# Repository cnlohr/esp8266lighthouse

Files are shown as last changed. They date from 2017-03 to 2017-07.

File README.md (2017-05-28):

# esp8266lighthouse

## Project log as of 5/28/17

So, general summary / log for esp8266lighthouse:   It works.  Surprisingly well.

1. If the base station is too close, it the signal quality gets pretty rough.   Too close = 0.8 meters or closer.  This may not be resolvable without a different opamp.  I don't know yet. 
2. There are some corner cases that will cause the ESP to freeze.  This is sad-making, however shouldn't be hard to troubleshoot.
3. The algorithm I'm using to determine frequency seems SLIGHTLY dependent on strength.  When pointed directly at the lighthouse and close, it seems to read slightly high (by about 10-15 kHz)  When at glancing angle or barely visible, it reads spot on.
4. The noise issue due to the ESP is really confusing to me.  Arbitrary moving something or switching power plugs around drastically changes the performance of the system.
5. The ESP8266 will draw ~14mA even in modem-sleep mode all the time if it is monitoring for a lighthouse.  This is sad.  I want to move to an FPGA, but because of the pinout on the ICE40 FPGAs and the fact they never put them in a reasonable package, PCBs for them cost about 10x what normal PCBs cost.
6. Though I can precisely tell frequencies, I cannot simultaneously decode pulses. Each pulse must have about 2uS between them in order to be treated as different pulses.   If we run lighthouses asynchronously, there will be some collisions.  They will need to be ignored.
7. The base stations CAN be run asynchronously and at different rates.  It seems to me that if the lighthouses are operating at the same frequency, they cannot disambiguate asynchronous pulses, but, we should be able to.

## Internal notes:

```
NOTES for transimpedence2/3
TESTS Performed with no C1, TSV992
Making R4 220k instead of 47k seeems to have little effect, but does make it worse.
Switching R1 for 47k just makes it appear drunk. There's some weird feedback thing going on.
    Like it tuned wrong or something.   Making it 10k quiets the signal a lot.
REMOVING C4 no apparent impact.

R5=10k, C5=10p -> R5=4.7k, C5=18p =>> Improvement.
Adding C1=1pF decreases amplitude a little bit but also cleans up edges.
Removing C6 seems to reduce amplitude slightly.

Far peak:
C1 none C6 none => .1238V noise, .998V Far Light
C1 none C6 1pF    => .1238V noise, .498V Far Light
C1 1pF  C6 none => .1135V noise, .358V Far Light
C1 1pF C6 1pF     => .087V Noise, .202V Far Light

Recommendation: Remove C6, C1.

Out of the following op amps...
TSH82, TSV992, AD8052, TSH22, TSH462,
TSV992 demolished.

Useful photodiodes:
PART / NOISE / FAR / Cost
PD70-01C/TR7:  .159 / .418 / .47
PD438C: .237 / .550 / .39
QSD2030F: .216 / .5363 / .30
BPW34/S-Z: .283 / .6345 /.497
PD15-216/TR8: UNUSABLE
VBPW34FAS: .175 / .815 / .778
VBPW34FASR: .2631 / .644 / .778
BPW34: .237 / .577 / .62
PD15-22C/TR8: Unworkable.
PD15-22B/TR8: Unworkable.
PD70-TR10: .2063 / .4024 / .41
BPW46: .247 / .968 / .61

Winners: BPW46, BPW34/S-Z, BPW34FAS + VBPW34FASR
Major Winners: BPW46/VBPW34FAS
```

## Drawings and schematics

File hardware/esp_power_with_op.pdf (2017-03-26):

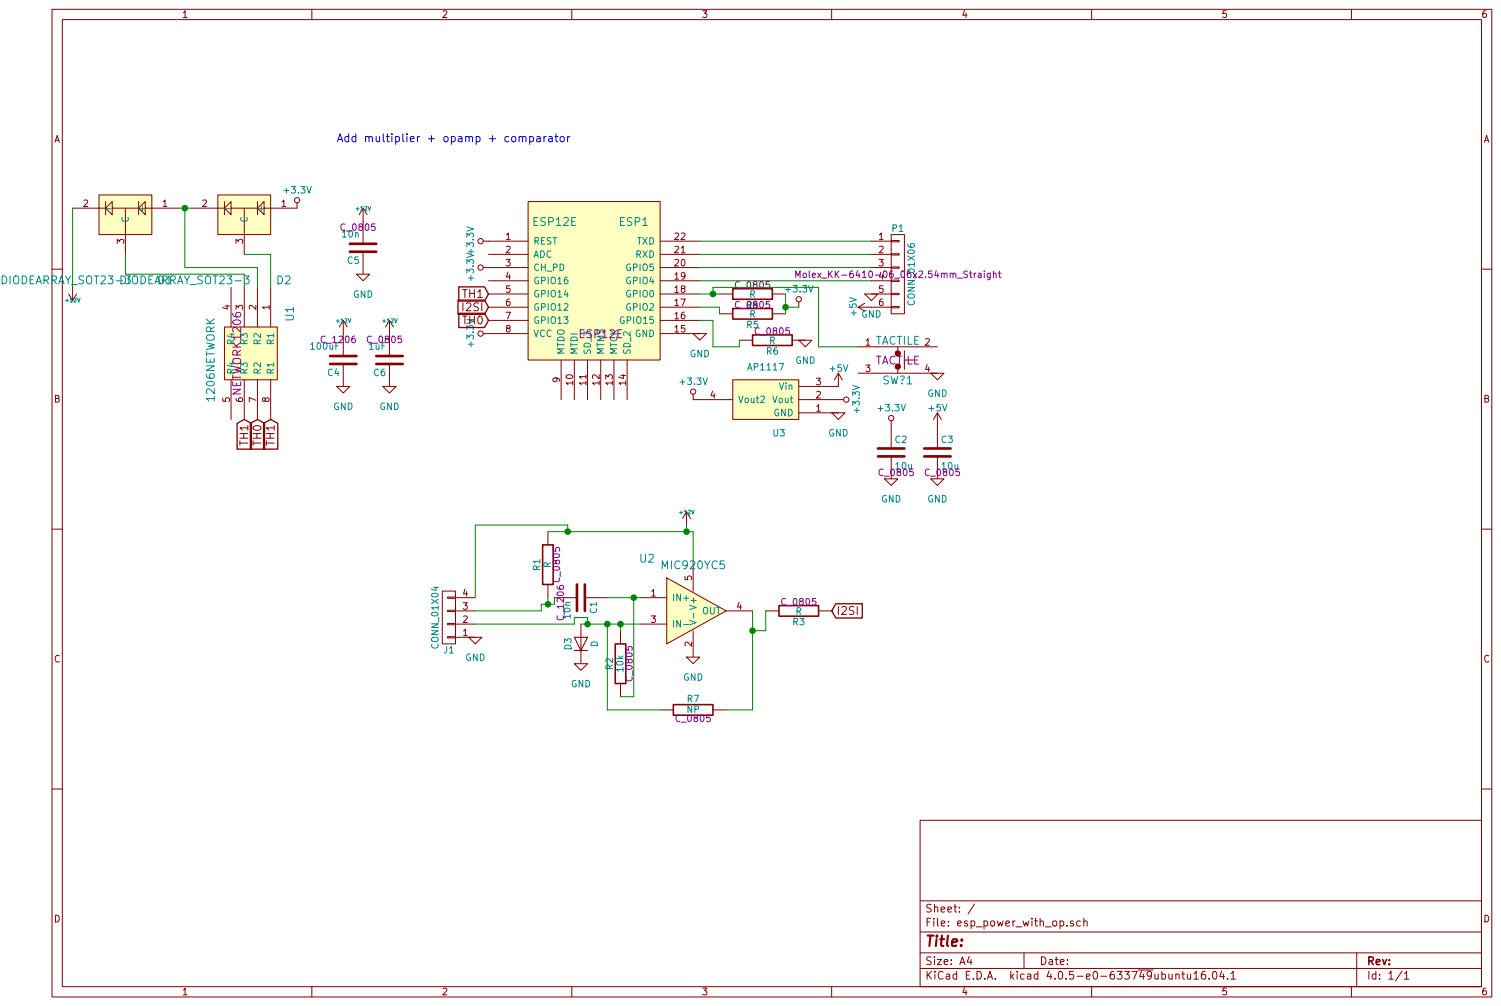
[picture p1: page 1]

9 MTDI 10 GPIO5 20 SD_3 11 RXD 21 MTMS 12 TXD 22 MTCK 13 SD_2 14 GND 15 GPIO15 16 GPIO2 17 GPIO0 18 GPIO4 19 ESP12E ESP1

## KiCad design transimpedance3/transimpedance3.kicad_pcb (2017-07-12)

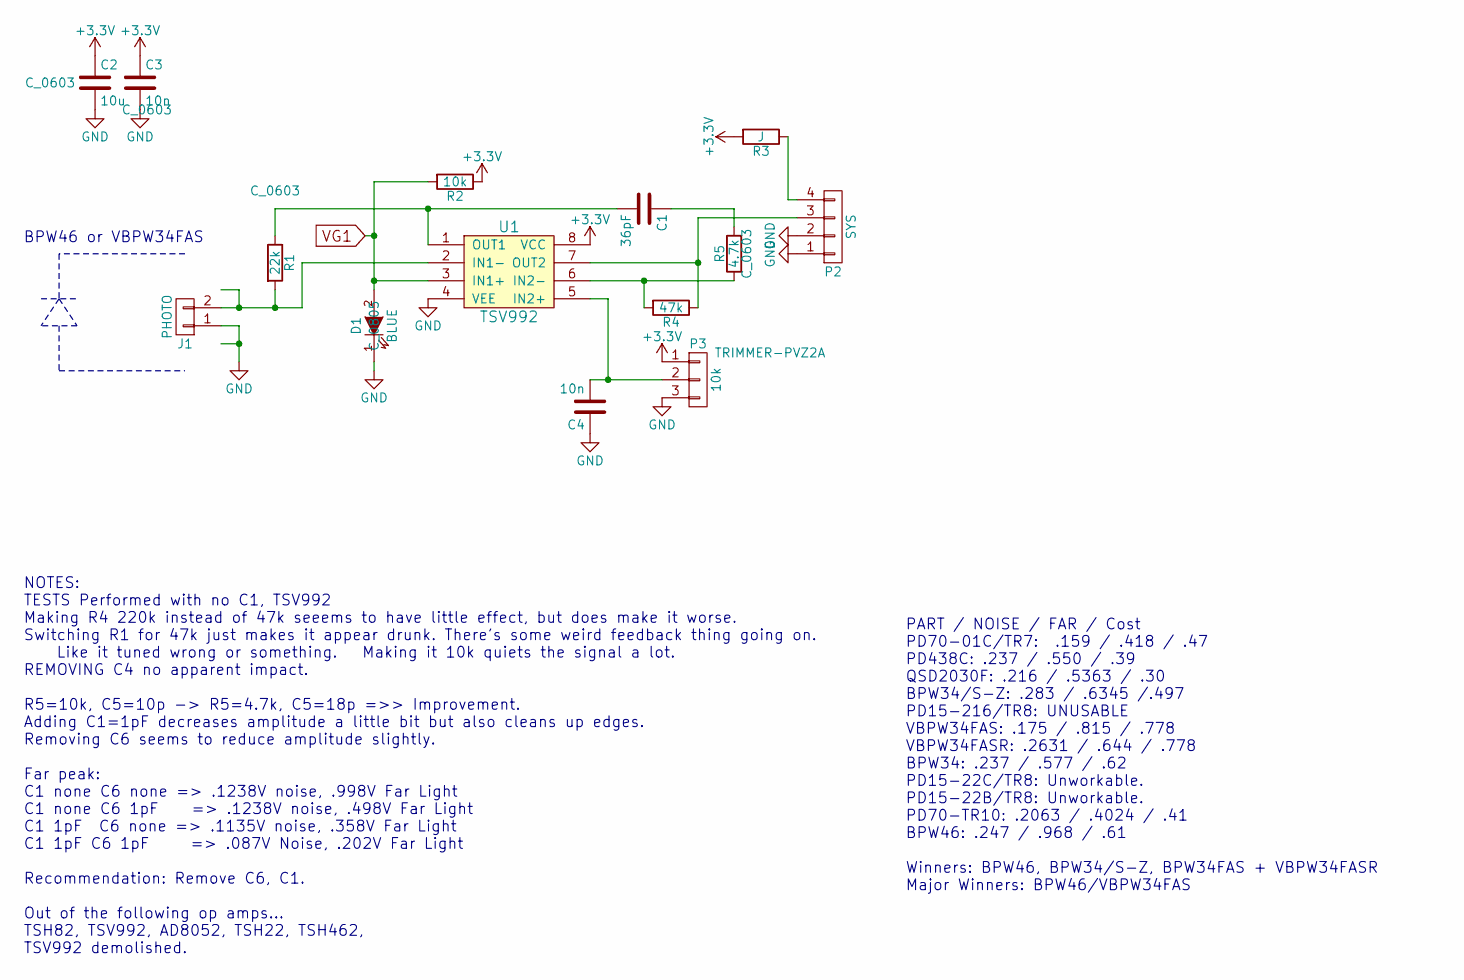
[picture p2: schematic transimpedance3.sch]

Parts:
C1: 36pF; C_0603
C2: 10u; C_0603
C3, C4: 10n; C_0603
D1: BLUE; C_0805
J1: PHOTO; Pin_Header_Straight_1x02_Pitch2.54mm
P2: SYS; TerminalBlock_Pheonix_MPT-2.54mm_4pol
P3: 10k; TRIMMER-PVZ2A
R1: 22k; C_0603
R2: 10k; C_0603
R3: J; C_0603
R4: 47k; C_0603
R5: 4.7k; C_0603
U1: TSV992; SSOP-8_2.95x2.8mm_Pitch0.65mm

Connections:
+3V3: C2.1, C3.1, P3.1, R2.1, R3.2, U1.8 (VCC)
GND: C2.2, C3.2, C4.1, D1.1 (K), J1.1, P2.1, P2.2, P3.3, U1.4 (VEE)
unnamed: C1.1, R5.2
unnamed: C1.2, R1.1, U1.1 (OUT1)
unnamed: C4.2, P3.2, U1.5 (IN2+)
unnamed: J1.2, R1.2, U1.2 (IN1-)
unnamed: P2.3, R4.1, U1.7 (OUT2)
unnamed: P2.4, R3.1
unnamed: R4.2, R5.1, U1.6 (IN2-)
VG1: D1.2 (A), R2.2, U1.3 (IN1+)

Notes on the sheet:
NOTES: TESTS Performed with no C1, TSV992 Making R4 220k instead of 47k seeems to have little effect, but does make it worse. Switching R1 for 47k just makes it appear drunk. There's some weird feedback thing going on. Like it tuned wrong or something. Making it 10k quiets the signal a lot. REMOVIN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
PART / NOISE / FAR / Cost PD70-01C/TR7: .159 / .418 / .47 PD438C: .237 / .550 / .39 QSD2030F: .216 / .5363 / .30 BPW34/S-Z: .283 / .6345 /.497 PD15-216/TR8: UNUSABLE VBPW34FAS: .175 / .815 / .778 VBPW34FASR: .2631 / .644 / .778 BPW34: .237 / .577 / .62 PD15-22C/TR8: Unworkable. PD15-22B/TR8: Unwork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
BPW46 or VBPW34FAS

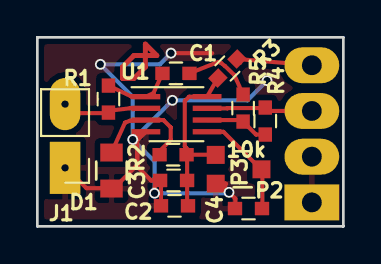
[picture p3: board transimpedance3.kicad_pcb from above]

Board: 2 copper layers, 17.0 x 10.5 mm, 14 parts (0 on the bottom side), 10 nets.

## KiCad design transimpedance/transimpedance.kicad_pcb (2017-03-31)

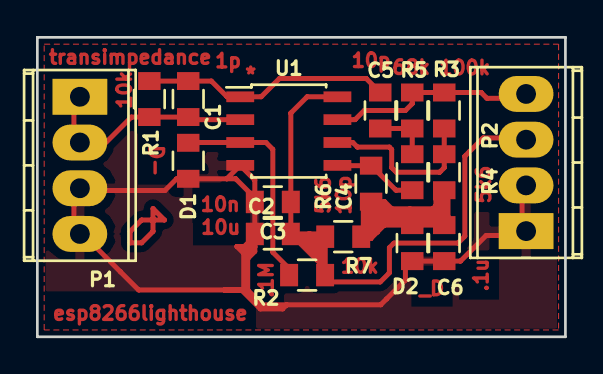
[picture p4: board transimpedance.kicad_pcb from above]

Board: 2 copper layers, 29.3 x 16.6 mm, 18 parts (0 on the bottom side), 10 nets.

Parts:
C1, C4, C5: 10p; C_0805
C2: 10u; C_0805
C3: 10n; C_0805
C6: 100n; C_0805
D1, D2: BLUE; C_0805
P1, P2: CONN_01X04; TerminalBlock_Pheonix_MPT-2.54mm_4pol
R1, R7: 10k; C_0805
R2: 100k; C_0805
R3: 106k; C_0805
R4, R6: 5.6k; C_0805
R5: 68k; C_0805
U1: DUALOPAMP; SOIC-8_3.9x4.9mm_Pitch1.27mm

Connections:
+3V3: C2.1, C3.1, P2.3, R2.1, R7.1, U1.8
GND: C2.2, C3.2, C6.2, D1.1, D2.1, P1.3, P1.4, P2.1, P2.2, U1.4
unnamed: C1.1, C5.1, R1.1, U1.1
unnamed: C1.2, P1.1, P1.2, R1.2, U1.2
unnamed: C4.1, C5.2, R5.1
unnamed: C4.2, R6.2, U1.5
unnamed: P2.4, R3.2, R5.2, U1.7
unnamed: R3.1, R4.2, U1.6
VG1: D1.2, R2.2, U1.3
VGND: C6.1, D2.2, R4.1, R6.1, R7.2

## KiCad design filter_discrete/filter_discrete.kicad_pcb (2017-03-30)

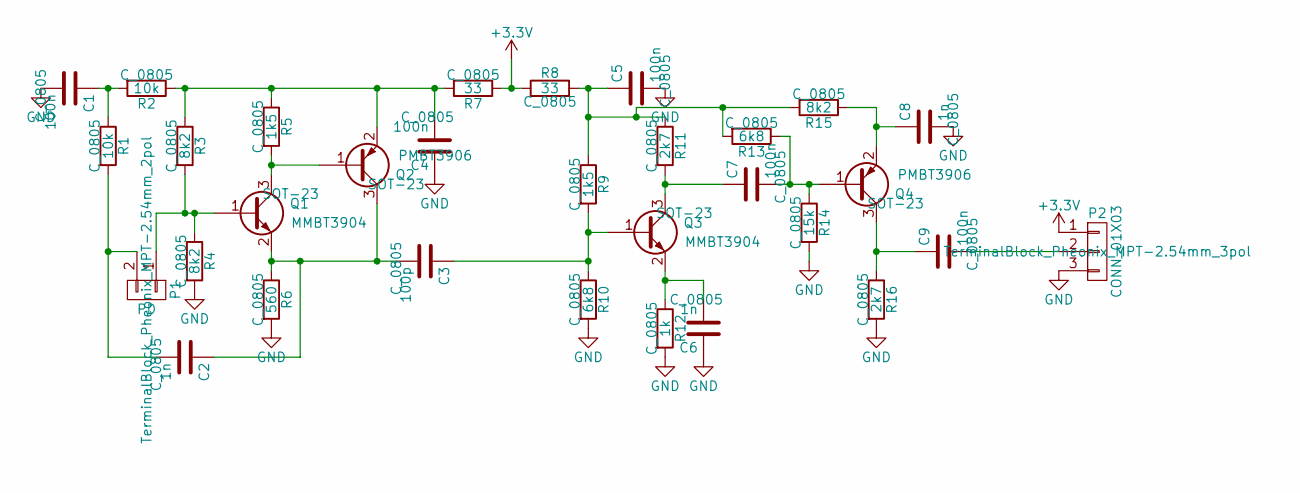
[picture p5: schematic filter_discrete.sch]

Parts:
C1, C4, C5, C7, C9: 100n; C_0805
C2, C6, C8: 1n; C_0805
C3: 100p; C_0805
P1: PD; TerminalBlock_Pheonix_MPT-2.54mm_2pol
P2: CONN_01X03; TerminalBlock_Pheonix_MPT-2.54mm_3pol
Q1, Q3: MMBT3904; SOT-23
Q2, Q4: PMBT3906; SOT-23
R1, R2: 10k; C_0805
R3, R4, R15: 8k2; C_0805
R5, R9: 1k5; C_0805
R6: 560; C_0805
R7, R8: 33; C_0805
R10, R13: 6k8; C_0805
R11, R16: 2k7; C_0805
R12: 1k; C_0805
R14: 15k; C_0805

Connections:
+3V3: P2.1, R7.1, R8.1
GND: C1.2, C4.1, C5.2, C6.1, C8.2, P2.3, R4.2, R6.2, R10.2, R12.2, R14.2, R16.2
unnamed: C1.1, R1.1, R2.2
unnamed: C2.1, C3.2, Q1.2 (E), Q2.3 (C), R6.1
unnamed: C2.2, P1.2, R1.2
unnamed: C3.1, Q3.1 (B), R9.2, R10.1
unnamed: C4.2, Q2.2 (E), R2.1, R3.1, R5.1, R7.2
unnamed: C5.1, R8.2, R9.1, R11.1, R13.2, R15.2
unnamed: C6.2, Q3.2 (E), R12.1
unnamed: C7.1, Q3.3 (C), R11.2
unnamed: C7.2, Q4.1 (B), R13.1, R14.1
unnamed: C8.1, Q4.2 (E), R15.1
unnamed: C9.1, Q4.3 (C), R16.1
unnamed: C9.2, P2.2
unnamed: P1.1, Q1.1 (B), R3.2, R4.1
unnamed: Q1.3 (C), Q2.1 (B), R5.2

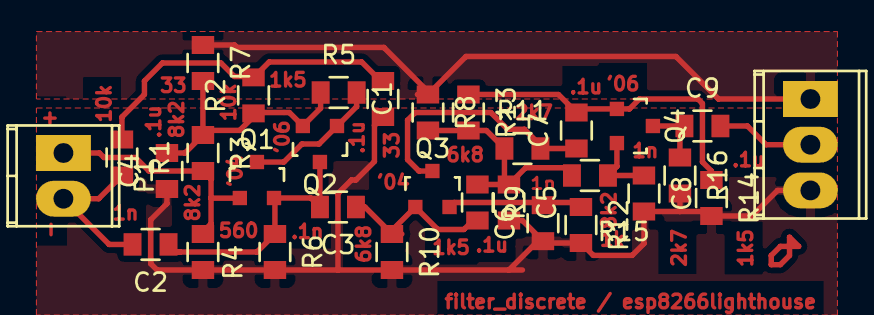
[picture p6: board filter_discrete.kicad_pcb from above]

Board: 2 copper layers, 31 parts (0 on the bottom side), 16 nets.

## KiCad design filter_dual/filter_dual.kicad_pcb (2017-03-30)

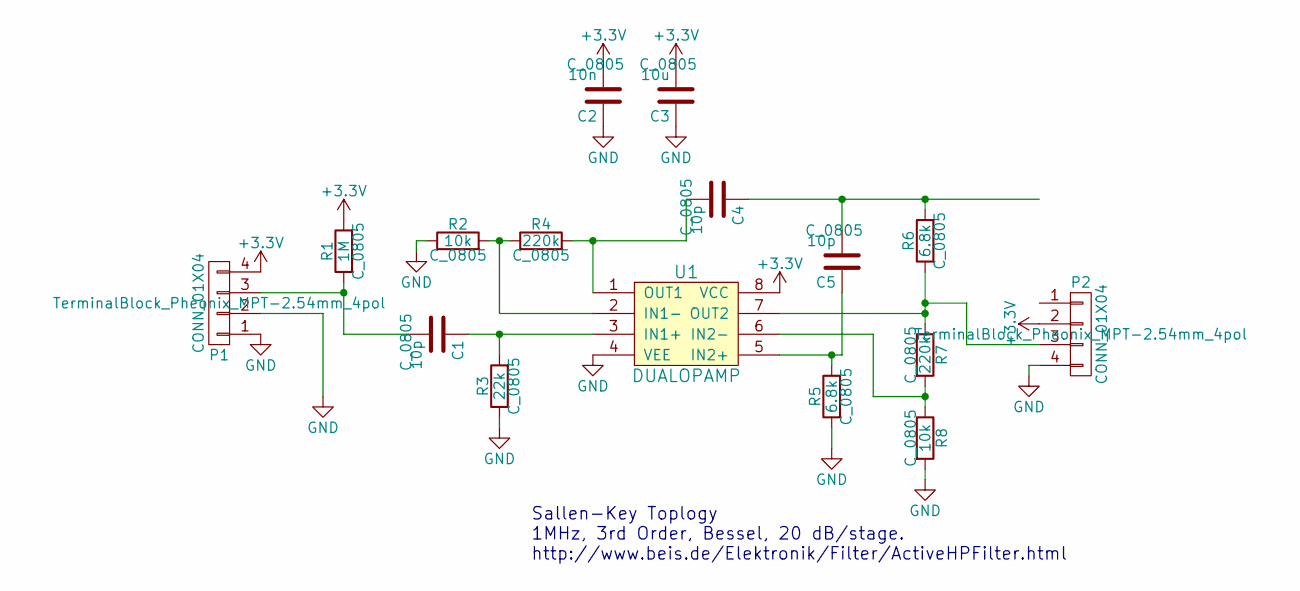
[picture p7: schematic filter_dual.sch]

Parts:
C1, C4, C5: 10p; C_0805
C2: 10n; C_0805
C3: 10u; C_0805
P1, P2: CONN_01X04; TerminalBlock_Pheonix_MPT-2.54mm_4pol
R1: 1M; C_0805
R2, R8: 10k; C_0805
R3: 22k; C_0805
R4, R7: 220k; C_0805
R5, R6: 6.8k; C_0805
U1: DUALOPAMP; SOIC-8_3.9x4.9mm_Pitch1.27mm

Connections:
+3V3: C2.2, C3.2, P1.4, P2.2, R1.2, U1.8 (VCC)
GND: C2.1, C3.1, P1.1, P1.2, P2.4, R2.1, R3.1, R5.1, R8.2, U1.4 (VEE)
unnamed: C1.1, R3.2, U1.3 (IN1+)
unnamed: C1.2, P1.3, R1.1
unnamed: C4.1, C5.2, R6.2
unnamed: C4.2, R4.2, U1.1 (OUT1)
unnamed: C5.1, R5.2, U1.5 (IN2+)
unnamed: P2.3, R6.1, R7.1, U1.7 (OUT2)
unnamed: R2.2, R4.1, U1.2 (IN1-)
unnamed: R7.2, R8.1, U1.6 (IN2-)

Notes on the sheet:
Sallen-Key Toplogy 1MHz, 3rd Order, Bessel, 20 dB/stage. http://www.beis.de/Elektronik/Filter/ActiveHPFilter.html

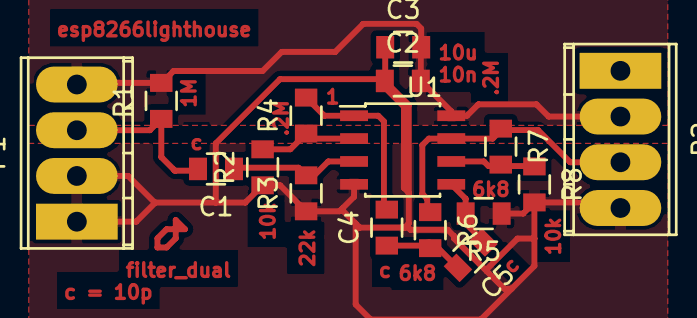
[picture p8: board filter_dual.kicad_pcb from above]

Board: 2 copper layers, 16 parts (0 on the bottom side), 10 nets.

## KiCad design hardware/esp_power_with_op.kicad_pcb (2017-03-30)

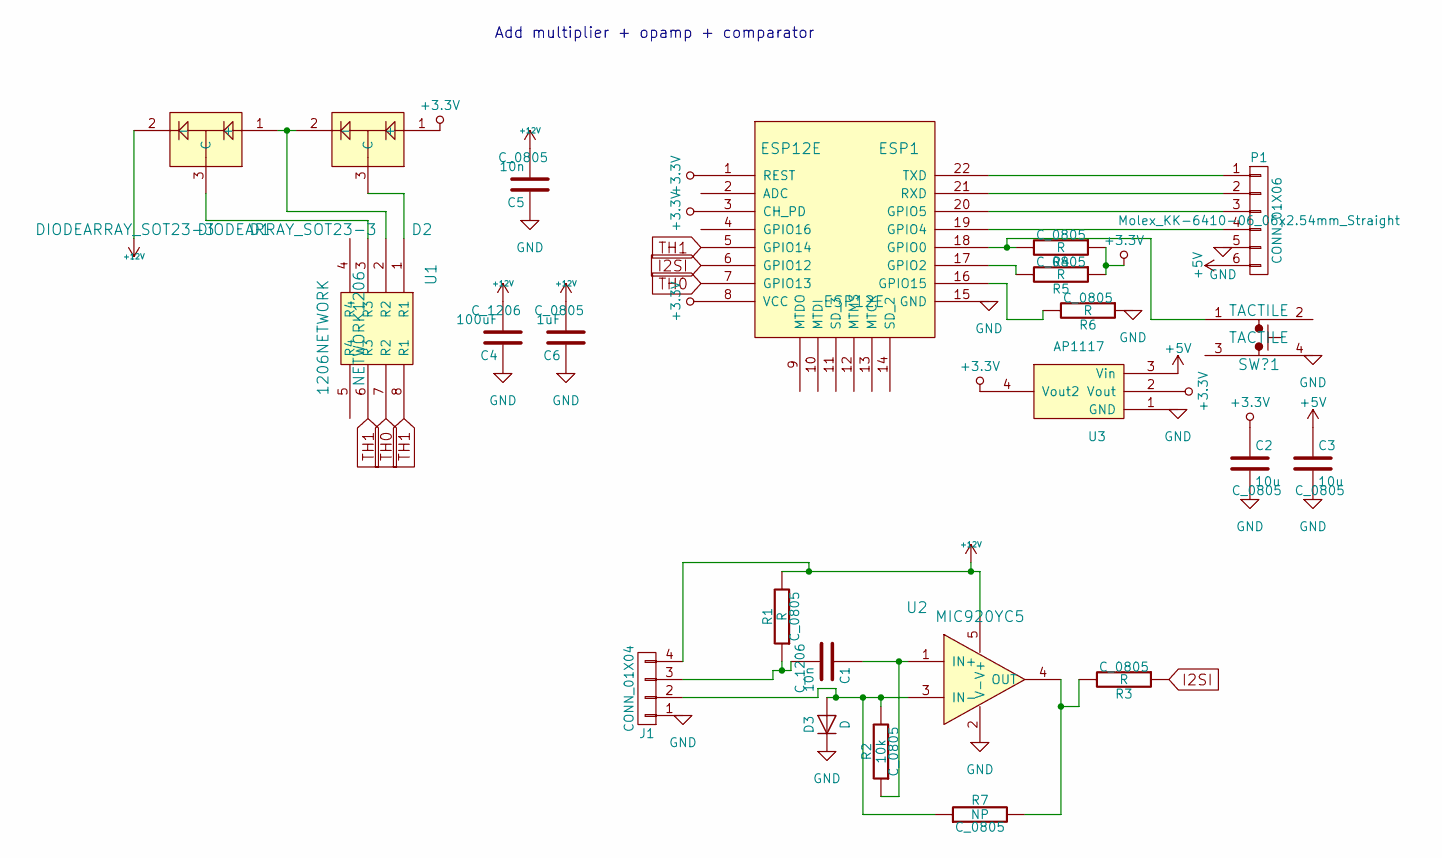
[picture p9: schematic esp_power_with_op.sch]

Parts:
C1: 10n; C_1206
C2, C3: 10u; C_0805
C4: 100uF; C_1206
C5: 10n; C_0805
C6: 1uF; C_0805
D1, D2: DIODEARRAY_SOT23-3; SOT-23
D3: D; C_1206
ESP1: ESP12E
J1: CONN_01X04; Molex_KK-6410-04_04x2.54mm_Straight
P1: CONN_01X06; Molex_KK-6410-06_06x2.54mm_Straight
R1, R3, R4, R5, R6: R; C_0805
R2: 10k; C_0805
R7: NP; C_0805
SW?1: TACTILE
U1: 1206NETWORK; NETWORK1206
U2: MIC920YC5; SOT-353_SC-70-5
U3: AP1117; SOT-223

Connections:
+3.3V: C2.1, D2.1 (+), ESP1.1 (REST), ESP1.3 (CH_PD), ESP1.8 (VCC), R4.1, R5.1, U3.2 (Vout), U3.4 (Vout2)
+5V: C3.1, P1.6, U3.3 (Vin)
+12V: C4.2, C5.2, C6.2, D1.2 (-), J1.4, R1.2, U2.5 (V+)
GND: C2.2, C3.2, C4.1, C5.1, C6.1, D3.1 (K), ESP1.15 (GND), J1.1, P1.5, R6.1, SW?1.4, U2.2 (V-), U3.1 (GND)
I2SI: ESP1.6 (GPIO12), R3.1
unnamed: C1.1, R2.1, U2.1 (IN+)
unnamed: C1.2, J1.3, R1.1
unnamed: D1.1 (+), D2.2 (-), U1.2 (R2)
unnamed: D1.3 (C), U1.3 (R3)
unnamed: D2.3 (C), U1.1 (R1)
unnamed: D3.2 (A), J1.2, R2.2, R7.1, U2.3 (IN-)
unnamed: ESP1.16 (GPIO15), R6.2
unnamed: ESP1.17 (GPIO2), R5.2
unnamed: ESP1.18 (GPIO0), R4.2, SW?1.1
unnamed: ESP1.19 (GPIO4), P1.4
unnamed: ESP1.20 (GPIO5), P1.3
unnamed: ESP1.21 (RXD), P1.2
unnamed: ESP1.22 (TXD), P1.1
unnamed: R3.2, R7.2, U2.4 (OUT)
TH0: ESP1.7 (GPIO13), U1.7 (R2)
TH1: ESP1.5 (GPIO14), U1.6 (R3), U1.8 (R1)

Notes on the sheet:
Add multiplier + opamp + comparator

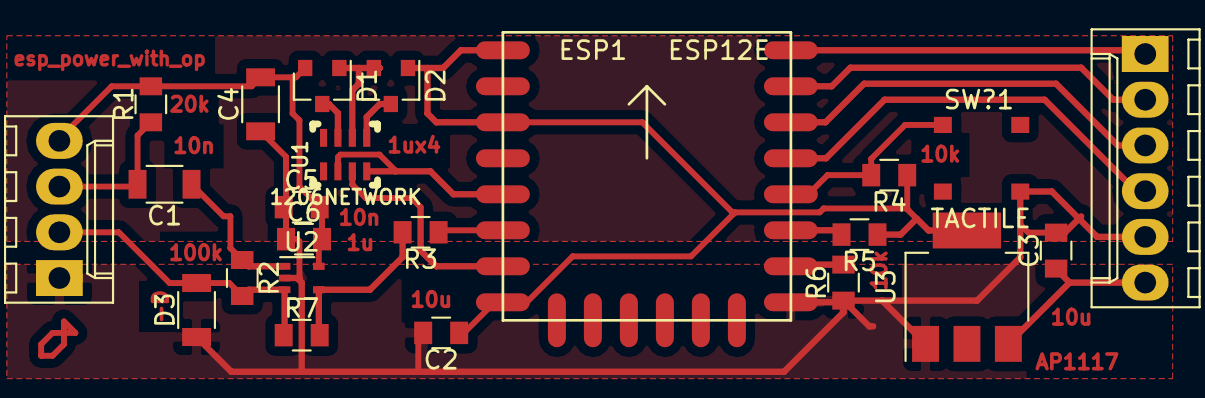
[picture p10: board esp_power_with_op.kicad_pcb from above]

Board: 2 copper layers, 23 parts (0 on the bottom side), 21 nets.

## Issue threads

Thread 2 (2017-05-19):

Make pulse detection span gaps

cnlohr, 2017-05-19:
With a single zero-frame, pulse detection terminates. It should probably span short gaps like this.

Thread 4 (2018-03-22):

Look into other opamps.

cnlohr, 2018-03-22:
Current:
TSV992:
Possible candidate TSH82:

One we're already on:
TSV992: $0.59410@100qty / 20MHz / 10V/us (MiniSO8, 3.0mm x 4.9mm, "rail to rail")
^^ Stable, reasonable, solid.

New:
TL082 : $0.27400@100qty / 4MHz / 16V/us (Available in 3x6.4mm package, significant voltage drop on output)
TSH72: Obsolete
TSH82: $0.78410 @100qty / 65MHz / 118V/us (SOIC, 4.5V to 12V operating range)

Single:
MIC920YC5-TR $0.2864@100qty / 80 MHz / 3000V/us  (+/-2.5V, minimum, but looks like almost a 2V drop in output stage)
MCP6S91T-E/MSCT-ND  : $0.68900@100qty  / 18MHz / 22V/us (NOPE)

cnlohr, 2018-03-22:
Odd but interesting...

Quad:
MCP669-E/ML - $1.6324@100qty / 60MHz/ 32 V/us (16QFN, Looks like pretty much rail-to-rail)

cnlohr, 2018-03-22:
Also, consider using a comparator like the MCP6564 as the final stage.   They are $1.1554 in quantity.

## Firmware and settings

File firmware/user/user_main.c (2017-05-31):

//Copyright 2015 <>< Charles Lohr, see LICENSE file.

#include "mem.h"
#include "c_types.h"
#include "user_interface.h"
#include "ets_sys.h"
#include <uart.h>
#include "osapi.h"
#include "espconn.h"
#include "i2sduplex.h"
#include <commonservices.h>
#include "lighthouse_decode.h"
#include <esp82xxutil.h>
#include <mdns.h>
#include <lighthouse_decode.h>


#define procTaskPrio        0
#define procTaskQueueLen    1


#define MAX_LH_CLIENTS 5
static volatile os_timer_t some_timer;
static struct espconn *pTcpListener;
static struct espconn *pTcpClients[MAX_LH_CLIENTS];
int                    pRREnds[MAX_LH_CLIENTS];
#define LEBUFFSIZE 256
volatile int pRRHead = 0;
struct LightEvent lebuffer[LEBUFFSIZE];


//int ICACHE_FLASH_ATTR StartMDNS();

void user_rf_pre_init(void)
{
	//nothing.
}


//Tasks that happen all the time.

os_event_t    procTaskQueue[procTaskQueueLen];

void ICACHE_FLASH_ATTR DumpAllConns()
{
	int i;
	for( i = 0; i < MAX_LH_CLIENTS; i++ )
	{
		espconn_disconnect(pTcpClients[i]);
		pTcpClients[i] = 0;
	}
}

static void ICACHE_FLASH_ATTR procTask(os_event_t *events)
{
	int ic;
	CSTick( 0 );

	//Check to see if we have any connected clients we can send data.
	int there_is_a_connection = 0;
	for( ic = 0; ic < MAX_LH_CLIENTS; ic++ )
	{		
		struct espconn * sock = pTcpClients[ic];
		if( sock )
		{
			there_is_a_connection = 1;
			int prrc = pRREnds[ic];
			if( TCPCanSend( sock, 1024 ) && prrc != pRRHead )
			{
				struct LightEvent les[64]; //Max 64 lighting events per packet.
				int i = 0;
				while( prrc != pRRHead && i < 64)
				{
					ets_memcpy( &les[i++], &lebuffer[prrc], sizeof( struct LightEvent ) );
					prrc = (prrc+1)%LEBUFFSIZE;
				}
				pRREnds[ic] = prrc;
				espconn_send( sock, (uint8_t*)&les[0], sizeof( struct LightEvent ) * i );
			}
		}
	}

	if( there_is_a_connection )
	{
		LHSM.debugmonitoring = 0;
		if( LHSM.debugbufferflag == 2 )
			LHSM.debugbufferflag = 0;
	}

	system_os_post(procTaskPrio, 0, 0 );
}

int SendPacket( struct LightEvent * data )
{
	ets_memcpy( &lebuffer[pRRHead], data, sizeof( struct LightEvent ) );
	pRRHead = (pRRHead+1)%LEBUFFSIZE;
	return 1;
}

//Timer event.
static void ICACHE_FLASH_ATTR myTimer(void *arg)
{
	CSTick( 1 );
}



void ICACHE_FLASH_ATTR charrx( uint8_t c )
{
	//Called from UART.
}




LOCAL void ICACHE_FLASH_ATTR
ptcp_disconnetcb(void *arg) {
    struct espconn *pespconn = (struct espconn *) arg;
	int ic = ((int)pespconn->reverse);
	pTcpClients[ic] = 0;
	printf( "Disconnect %d\n", ic );
}

LOCAL void ICACHE_FLASH_ATTR ptcp_recvcb(void *arg, char *pusrdata, unsigned short length)
{
    struct espconn *pespconn = (struct espconn *) arg;
	int ic = (int)pespconn->reverse;
	printf( "Receive %d\n", ic );
	//TODO: Handle commands on tcp port.
}

void ICACHE_FLASH_ATTR ptcp_connect_listener(void *arg)
{

	int i;
    struct espconn *pespconn = (struct espconn *)arg;

	for( i = 0; i < MAX_LH_CLIENTS; i++ )
	{
		if( pTcpClients[i] == 0 )
		{
			pespconn->reverse = (void*)i;
			pTcpClients[i] = pespconn;
			pRREnds[i] = pRRHead;
			break;
		}
	}
	if( i == MAX_LH_CLIENTS )
	{
		espconn_disconnect( pespconn );
		return;
	}

	printf( "New conn %d\n", i );

	//http://bbs.espressif.com/viewtopic.php?f=21&t=320
	espconn_set_opt(pespconn, 0x04); // enable write buffer
	//Doing this allows us to queue writes in the socket, which
	//SIGNIFICANTLY speeds up transfer in Windows.

	//espconn_regist_write_finish( pespconn, http_sentcb );
    espconn_regist_recvcb( pespconn, ptcp_recvcb );
    espconn_regist_disconcb( pespconn, ptcp_disconnetcb );
}

void ICACHE_FLASH_ATTR user_init(void)
{
	uart_init(BIT_RATE_115200, BIT_RATE_115200);
//	ets_delay_us(200000 );
	uart0_sendStr("\r\nesp8266 ws2812 driver\r\n");


//	int opm = wifi_get_opmode();
//	if( opm == 1 ) need_to_switch_opmode = 120;
//	wifi_set_opmode_current(2);
//Uncomment this to force a system restore.
//	system_restore();

	CSSettingsLoad( 0 );
	CSPreInit();

	//Configure buffers
	lighthouse_setup();

	pTcpListener = (struct espconn *)os_zalloc(sizeof(struct espconn));
	ets_memset( pTcpListener, 0, sizeof( struct espconn ) );
	espconn_create( pTcpListener );
	pTcpListener->type = ESPCONN_TCP;
    pTcpListener->state = ESPCONN_NONE;
	pTcpListener->proto.tcp = (esp_tcp *)os_zalloc(sizeof(esp_tcp));
	pTcpListener->proto.tcp->local_port = 10900;
    espconn_regist_connectcb(pTcpListener, ptcp_connect_listener);
    espconn_accept(pTcpListener);
    espconn_regist_time(pTcpListener, 15, 0); //timeout

	CSInit();

	SetServiceName( "lighthouse" );
	AddMDNSName( "esp82xx" );
	AddMDNSName( "lighthouse" );
	AddMDNSService( "_http._tcp", "An ESP8266 Webserver", 80 );
	AddMDNSService( "_lighthouse._tcp", "Lighthouse data source", 10900 );
	AddMDNSService( "_cn8266._udp", "ESP8266 Backend", 7878 );

	//Add a process
	system_os_task(procTask, procTaskPrio, procTaskQueue, procTaskQueueLen);

	//Timer example
	os_timer_disarm(&some_timer);
	os_timer_setfn(&some_timer, (os_timer_func_t *)myTimer, NULL);
	os_timer_arm(&some_timer, 60, 1);

	//Configure 
	testi2s_init();

	PIN_FUNC_SELECT(PERIPHS_IO_MUX_MTCK_U, FUNC_GPIO13);
	PIN_FUNC_SELECT(PERIPHS_IO_MUX_MTMS_U, FUNC_GPIO14);

	PIN_DIR_OUTPUT = _BV(13) | _BV(14);
	PIN_OUT_SET = _BV(13) | _BV(14);

	//Configure the charge pump pins.

	system_update_cpu_freq( SYS_CPU_160MHZ );

	system_os_post(procTaskPrio, 0, 0 );
}


//There is no code in this project that will cause reboots if interrupts are disabled.
void EnterCritical()
{
}

void ExitCritical()
{
}

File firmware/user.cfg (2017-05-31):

###############################################################################
# User Options
###############################################################################

CHIP  = 8266
IP    = 192.168.4.1     # does not actually set the IP in firmware
PORT  = /dev/ttyUSB0    # could also be /dev/ttyACM0
WEB_PORT     = 80
COM_PORT     = 7777
BACKEND_PORT = 7878
PAGE_OFFSET  = 65536     # 1048576

SRCS += user/i2sduplex.c \
	user/lighthouse_decode.c \
	user/lighthouse_i2s_lut.c

FWBURNFLAGS  = -b 1500000

SDK_DEFAULT  = $(HOME)/esp8266/esp-open-sdk
ESP_GCC_VERS = 4.8.5

#FLASH_WRITE_FLAGS += 0x3FC000 esp_init_data_default.bin

OPTS += -DICACHE_FLASH
#OPTS += -DVERIFY_FLASH_WRITE
#OPTS += -DDEBUG
#OPTS += -DNET_MAXTRIES=10
#OPTS += -DNET_TIMEOUT=3.0
#OPTS += -DFREQ=12500
OPTS+=-g

PAGE_TITLE = esp82xx-basic
PAGE_SCRIPTS = $(wildcard page/*.js) # include all javascrpts in ./web/page/
PAGE_HEADING = Welcome to the basic Web-GUI
PAGE_INFO = This is the basic web interface for esp82xx-series chips

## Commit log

2017-03-26 Add all parts to this repo.
    [esp_power_with_op.kicad_pcb, esp_power_with_op.sch, kelvindmmwifi.kicad_pcb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]
2017-03-26 remove chage pump etc
2017-03-26 Update - swapping files aroundo
    [esp_power_with_op.sch, kelvindmmwifi.kicad_pcb, kelvindmmwifi.sch]
2017-03-30 Add other filters.
    [filter_discrete.kicad_pcb, filter_discrete.sch, filter_dual.kicad_pcb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]
2017-03-30 add updated files
    [esp_power_with_op.kicad_pcb]
2017-03-30 update lighthouse designs
    [esp_power_with_op.sch, filter_discrete.kicad_pcb, filter_dual.kicad_pcb]
2017-03-31 update transimpedence filter.
    [transimpedance.kicad_pcb, transimpedance.sch]
2017-04-04 update with transimpedance 2
    [transimpedance2.kicad_pcb, transimpedance2.sch]
2017-05-01 update the transimpedance esign.
    [transimpedance2.kicad_pcb]
2017-05-11 update transimpedance3
    [transimpedance3.kicad_pcb, transimpedance3.sch]
2017-05-11 update tia3
    [transimpedance3.sch]
2017-05-12 Update all designs with newest to fab.
    [transimpedance3.kicad_pcb, transimpedance3.sch]
2017-05-12 update schematic
    [transimpedance3.sch]
2017-05-15 Update the esp8266 lighthouse code to allow browser-interaction.
    [user.cfg]
2017-05-15 cleanup styles on website, plus, remove the I2S TX engine. Hopefully this will relieve some DMA contention.
    [user.cfg]
2017-05-18 Closing in on a solution!!!
    [user.cfg]
2017-05-18 Working successfully with web gui (Also update project for kicad)
2017-05-18 Update with fully functional tracking code and sending over UDP (though there is some debt that need be handled)
    [histogram.ods]
2017-05-18 Issues with the DMA buffer system in the ESP. Must be fixed. Other than that, getting very close.
    [user_main.c]
2017-05-18 fix bug with bad scoping.
    [histogram.ods]
2017-05-27 Transition over to TCP for main transport mechanism.
    [user.cfg]
2017-05-27 Fix bug in FDM decoding for 1.2 MHz specifically.
    [user_main.c]
2017-05-30 Update processing, etc. to include transition values.
    [outdata.tsv, straighttest3.csv]
2017-05-30 Add minimize error
    [minimizeerror.ods]
2017-05-31 Fix crash in lighthouse decode with possible negative indexes.
    [user.cfg]
2017-07-12 bump revision
    [transimpedance3.kicad_pcb]
